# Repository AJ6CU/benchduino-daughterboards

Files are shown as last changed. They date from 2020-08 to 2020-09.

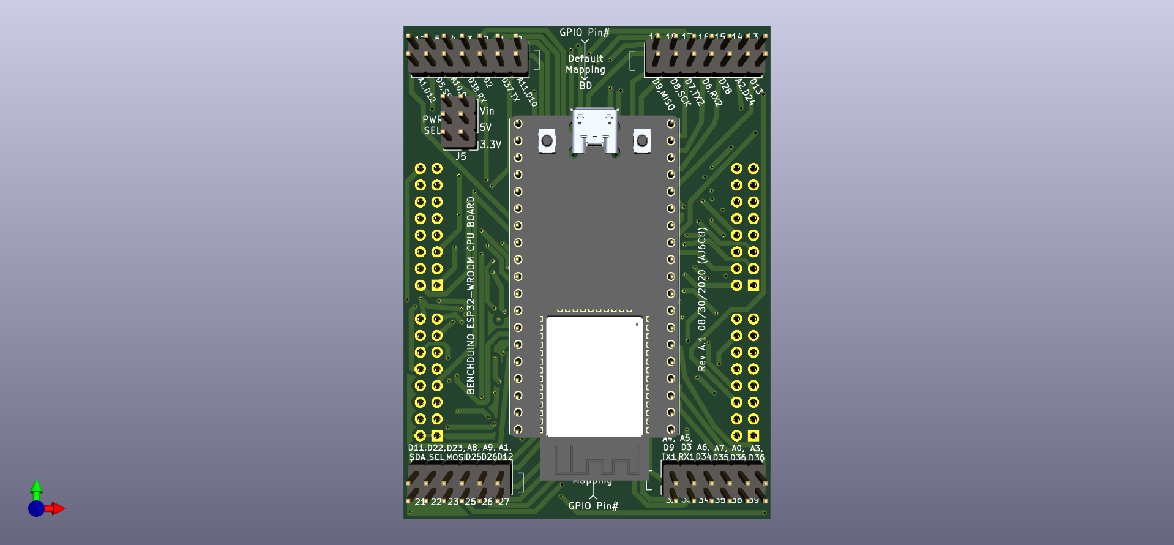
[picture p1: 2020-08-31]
ESP32-WROOM/Documentation/BenchDuino ESP32-WROOM-32 CPU Board.png

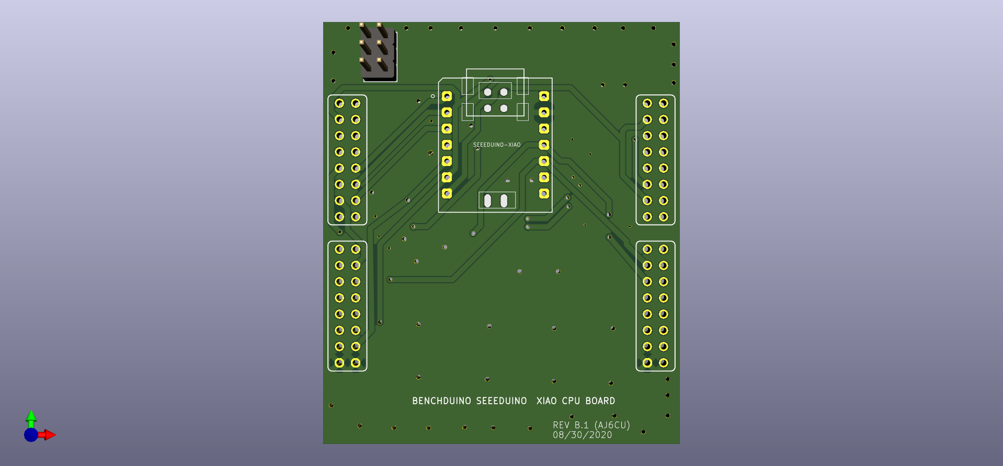
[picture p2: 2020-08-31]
Seeeduino XIAO/Documentation/Seeeduino XIAO CPU Board.png

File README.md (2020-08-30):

# CPU Daughterboards Benchduino
 
www.hamradioworkbench.com has designed and sells a general purpose development
board for Microcontrollers. They have provided the designs for both the CPU
Daughterboards as wells as the addon Prototype board.

This repository contains additional CPU Daughterboards that I have designed.

Subdirectories include:
- Gerbers - this directory includes a zip file that you should be able to upload to
            your favorite Fab house.
- PCBDesign - Most of the designs are done with KiCad. A few of the earlier ones
            were done with Eagle. The subdirectory will indentify which tool was used. 
- Documentation - This directory contains a schematic (pdf format) and pinmapping between
            the Benchduino pins and the pins on the Microcontroller. Please note that
            some physical pins on the Microcontroller might be mapped to multiple 
            locations on the Benchduino. Please use this pinmapping document along
            with your favorite pinout diagram to understand which pins could cause
            conflicts.
- Examples - Generally I have provide a code example (typically derived from the
            original Hamvention code of the published on the hamradioworkbench site)

There is absolutely no warranty here. Use this at your own risk!

73
Mark Hatch
AJ6CU

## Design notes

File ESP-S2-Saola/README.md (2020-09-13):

# ESP-S2-Saola CPU Daughterboard for Benchduino
 
www.hamradioworkbench.com has designed and sells a general purpose development
board for Microcontrollers. They have provided the designs for both the CPU
Daughterboards as wells as the addon Prototype board.

This directory contains the CPU Daughterboards for the ESP-S2-Saola processor.

*IMPORTANT*
There are many different versions of the ESP32. This design was built around:

https://www.amazon.com/gp/product/B087T2NTD6/ref=ppx_yo_dt_b_search_asin_title?ie=UTF8&psc=1

Just because your board has the same number of pins, it may not work...  There are also 
different widths of boards, the latter ones being slightly wider.

Subdirectories include:
- Gerbers - this directory includes a zip file that you should be able to upload to
            your favorite Fab house.
- PCBDesign - Most of the designs are done with KiCad. A few of the earlier ones
            were done with Eagle. The subdirectory will indentify which tool was used. 
- Documentation - This directory contains a schematic (pdf format) and pinmapping between
            the Benchduino pins and the pins on the Microcontroller. Please note that
            some physical pins on the Microcontroller might be mapped to multiple 
            locations on the Benchduino. Please use this pinmapping document along
            with your favorite pinout diagram to understand which pins could cause
            conflicts.
- Examples - Generally I have provide a code example (typically derived from the
            original Hamvention code of the published on the hamradioworkbench site).
            Make sure you read the "README" file in this directory as often there are
            significant porting issues that you might need to be aware of in your
            own applications.

There is absolutely no warranty here. Use this at your own risk!

73
Mark Hatch
AJ6CU

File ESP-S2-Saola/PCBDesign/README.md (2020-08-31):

# ESP-S2-Saola CPU Daughterboard for Benchduino
 
www.hamradioworkbench.com has designed and sells a general purpose development
board for Microcontrollers. They have provided the designs for both the CPU
Daughterboards as wells as the addon Prototype board.

This directory contains the design files for the ESP-S2-Saola CPU Daughterboard. This
design was done in KiCad.

The zip file is a KiCad archive that you shoule be able to just expand.

There is absolutely no warranty here. Use this at your own risk!

73
Mark Hatch
AJ6CU

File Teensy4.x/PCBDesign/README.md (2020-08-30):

# Teensy 4/4.1 CPU Daughterboard for Benchduino
 
www.hamradioworkbench.com has designed and sells a general purpose development
board for Microcontrollers. They have provided the designs for both the CPU
Daughterboards as wells as the addon Prototype board.

This directory contains the design files for the Teensy 4/4.1 CPU Daughterboards. This
design was done in Eagle.

There is absolutely no warranty here. Use this at your own risk!

73
Mark Hatch
AJ6CU

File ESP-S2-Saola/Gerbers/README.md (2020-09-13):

# ESP-S2-Saola CPU Daughterboard for Benchduino
 
www.hamradioworkbench.com has designed and sells a general purpose development
board for Microcontrollers. They have provided the designs for both the CPU
Daughterboards as wells as the addon Prototype board.

This directory contains a Zip file with the Gerbers for the CPU Daughterboard for a 
ESP-S2-Saola processor.

This design has been fabricated using these Gerbers and successfully runs the 
Hamvention demo program.

There is absolutely no warranty here. Use this at your own risk!

73
Mark Hatch
AJ6CU

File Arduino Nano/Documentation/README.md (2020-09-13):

# Documentation for Arduino Nano CPU Daughterboard
 
www.hamradioworkbench.com has designed and sells a general purpose development
board for Microcontrollers. They have provided the designs for both the CPU
Daughterboards as wells as the addon Prototype board.

This directory contains the documentation for this design. Including: 
- Schematic (pdf format) 
- Pinmapping between the Benchduino pins and the pins on the Microcontroller. 
            to multiple locations on the Benchduino. Please use this pinmapping 
            document along with your favorite pinout diagram to understand which 
            pins could cause
            conflicts.
            
*IMPORTANT NOTE ON POWER*
This microcontroller has 2 jumpers at the top of the board that allow you to select
which power is fed to the board *AND* whether in the case where the processor is
being powered by USB, the 5V is passed back to the Benchduino motherboard.

NOTE: Generally it is not recommended to power the processor from USB *and* also via
the 5v/3v/Vin power. 

Vin: This pin should generally not be jumpered unless you know what you are doing. When
jumpered, it provides power to the processor. The only problem is that the Benchduino
motherboard *does not* provide power to this pin. It is left floating. So if you want to
use this pin, perhaps because you are using a battery, you *must* provide your own power
to this pin.

5+: This pin is both input and output. When the motherboard of the benchduino is powered
(i.e. a power source is plugged into the barrel connector) 5V is delivered to the
daughterboard. However, in the case where the processor is being powered by the USB
connection, the 5V from the USB is distributed *to* the benchduino motherboard and
used to power various devices you might have. 

However...
you might want to consider removing this jumper if you are powering the processor
by USB and *do not* want the peripherals driven off this power source because of the current
drain. In such a case, remove this jumper and power the Benchduino via the barrel
connector.

NOTE: Even though some people have hacked their Nano to run on 3.3v (involves lowering
clock speed plus more - google it), I did not connect 3.3V in. If you want to run your
Nano on something other than the 5V spec, you can use the Vin pin on the Benchduino
motherboard and then jumper the Vin pin described above.

There is absolutely no warranty here. Use this at your own risk!

73
Mark Hatch
AJ6CU

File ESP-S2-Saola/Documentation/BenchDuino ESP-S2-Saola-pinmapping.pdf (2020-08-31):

ESP32 Saola Pin Mapping to Benchduino

<------------------------------------------Saola------------------------------------------><-------------BD------------>
Pin# | GPIO# | Analog | Analog Ch | Spc Analog | Special | Analog | Digital | SPC
1 | 3.3v
2 | GPIO00
3 | GPIO01 | 0 | ADC1_CH0 | Touch1 | | 0
4 | GPIO02 | 1 | ADC1_CH1 | Touch2 | | 1 | 2
5 | GPIO03 | 2 | ADC1_CH2 | Touch3 | | 2 | 3
6 | GPIO04 | 3 | ADC1_CH3 | Touch4 | | 3 | 4
7 | GPIO05 | 4 | ADC1_CH4 | Touch5 | | 4 | 5
8 | GPIO06 | 5 | ADC1_CH5 | Touch6 | | 5 | 6
9 | GPIO07 | 6 | ADC1_CH6 | Touch7 | | 6 | 7
10 | GPIO08 | 7 | ADC1_CH7 | Touch8 | | 7 | 8
11 | GPIO09 | 8 | ADC1_CH8 | Touch9 | | 8 | 9
12 | GPIO10 | 9 | ADC1_CH9 | Touch10 | | 9 | 10
13 | GPIO11 | 10 | ADC2_CH0 | Touch11 | | 10 | 11 | CS
14 | GPIO12 | 11 | ADC2_CH1 | Touch12 | | 11 | 12 | MOSI
15 | GPIO13 | 12 | ADC2_CH2 | Touch13 | | | 13 | CLK
16 | GPIO14 | 13 | ADC2_CH3 | Touch14 | | | 24 | MISO
17 | GPIO15 | 14 | ADC2_CH4 | XTAL_32k_P | U0RTS | | 25
18 | GPIO16 | 15 | ADC2_CH5 | XTAL_32k_N | U0CTS | | 26
19 | GPIO17 | 16 | ADC2_CH6 | DAC1 | U1TXD | | 27 | TX1
20 | 5.0Vin
21 | Gnd
22 | GPIO18 | 17 | ADC2_CH7 | DAC2 | U1RXD | | 28 | RX1
23 | GPIO19 | 18 | ADC2_CH8 | USB_D- | U1RTS | | 29
24 | GPIO20 | 19 | ADC2_CH9 | USB_D+ | U1CTS | | 30
25 | GPIO21 | | | | | | 31
26 | GPIO26 | | | | | | 32
27 | GPIO33 | | | | | | 33
28 | GPIO34 | | | | | | 34
29 | GPIO35 | | | | | | 35
30 | GPIO36 | | | | | | 36
31 | GPIO37 | | | | | | 37
32 | GPIO38 | | | | | | 38
33 | GPIO39 | | | | | | 22 | SDA
34 | GPIO40 | | | | | | 23 | SCL
35 | GPIO41
36 | GPIO42
37 | GPIO43 | | | | U0TX0 | | | TX
38 | GPIO44 | | | | U0RX0 | | | RX
39 | GPIO45
40 | GPIO46
41 | Reset
42 | Gnd

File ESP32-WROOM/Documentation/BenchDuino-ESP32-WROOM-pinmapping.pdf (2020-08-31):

ESP32 WROOM Pin Mapping to Benchduino

<--------------------ESP32-WROOM--------------------> | <-------------------BD----------------->
Pin# | GPIO | Analog | SPC | Analog | Digital | SPC
25 | GPIO0 | ADC11 | | 11 | 10
35 | GPIO1 | | TX0 | | 37 | TX
24 | GPIO2 | ADC12 | | X | 2
34 | GPIO3 | | RX0 | | 38 | RX
26 | GPIO4 | ADC10 | | 10 | 4
29 | GPIO5 | | SS | | 5 | SS
20 | GPIO6
21 | GPIO7
22 | GPIO8
16 | GPIO9 | | RX1
17 | GPIO10 | | TX1
18 | GPIO11
13 | GPIO12 | ADC15 | | 1 | 12
15 | GPIO13 | ADC14 | | X | 13
12 | GPIO14 | ADC16 | | 2 | 24
23 | GPIO15 | ADC13 | | X | 28
27 | GPIO16 | | RX2 | | 6 | RX2
28 | GPIO17 | | TX2 | | 7 | TX2
30 | GPIO18 | | SCK | | 8 | SCK
31 | GPIO19 | | MISO | | 29 | MISO
33 | GPIO21 | | SDA | | 11 | SDA
36 | GPIO22 | | SCL | | 22 | SCL
37 | GPIO23 | | MOSI | | 23 | MOSI
9 | GPIO25 | ADC18 | | 8 | 25
10 | GPIO26 | ADC19 | | 9 | 26
11 | GPIO27 | ADC17 | | x | 27
7 | GPIO32 | ADC4 | | 4 | 9 | TX1
8 | GPIO33 | ADC5 | | 5 | 3 | RX1
5 | GPIO34 | ADC6 | | 6 | 34
6 | GPIO35 | ADC7 | | 7 | 35
3 | GPIO36 | ADC0 | | 0 | 36
4 | GPIO39 | ADC3 | | 3 | 33

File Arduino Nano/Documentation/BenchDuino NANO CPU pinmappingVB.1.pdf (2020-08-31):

Nano Pin Mapping to Benchduino

Nano Pin | BD Analog | BD Digital | BD Special
A0 | A0
A1 | A1
A2 | A2
A3 | A3
A4 | A4 | | SDA
A5 | A5 | | SCL
A6 | A6
A7 | A7
AREF | | | REF
D0 | | | RX
D1 | | | TX
D2 | | D2
D3 | | D3
D4 | | D4
D5 | | D5
D6 | | D6
D7 | | D7
D8 | | D8
D9 | | D9
D10 | | D10 | SS
D11 | | D11 | MOSI
D12 | | D12 | MISO
D13 | | D13 | SCK

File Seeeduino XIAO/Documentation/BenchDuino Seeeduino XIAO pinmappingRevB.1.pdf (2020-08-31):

Xiao Pin Mapping to Benchduino

XIAO Pin | BD Analog | BD Digital | BD Special
A0 | A0
A1 | A1
A2 | A2 | D2
A3 | A3 | D3
A4 | A4 | D4 | SDA
A5 | A5 | D5 | SCL
A6 | A6 | D6 | TX
A7 | A7 | D7 | RX
A8 | A8 | D8 | SCK
A9 | A9 | D9 | MISO
A10 | A10 | D10 | MOSI

Note: D0 and D1 are connected to A0 and A1 and not the usual RX and TX pins

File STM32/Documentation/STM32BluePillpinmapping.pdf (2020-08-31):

BluePill Pin Mapping to Benchduino

stm32 pin BD Analog BD Digital BD Special PA0
PA1
PA2 | A2 | D2 | TX2
PA3 | A3 | D3 | RX2
PA4 | A4 | D4 | SS1
PA5 | A5 | D5 | SCK1
PA6 | A6 | D6 | MISO1
PA7 | A7 | D7 | MOSI1
PA8 | | D8
PA9 | | D9 | TX1
PA10 | | D10 | RX1
PA11 | | D11
PA12 | | D12
PA13 | NC - Serial programming header
PA14 | NC - Serial programming header
PA15 | See Extra hdr
PB0 | See Extra hdr
PB1 | See Extra hdr
PB2 | NC - Boot programming header
PB3 | | D23
PB4 | | D24
PB5 | | D25
PB6 | | D26 | SCL1
PB7 | | D27 | SDA1
PB8 | | D28
PB9 | | D29
PB10 | | D30 | TX3
PB11 | | D31 | RX3
PB12 | | D32
PB13 | | D33
PB14 | | D34
PB15 | | D35

Extra Header
PA0
PA1
PA15
PB0
PB1
PC13
PC14
PC15

VBAT
GND

Benchduino with No connections
NC | D13
NC | D22
NC | D36
NC | D37
NC | D38
NC | A8
NC | A9
NC | A10
NC | A11

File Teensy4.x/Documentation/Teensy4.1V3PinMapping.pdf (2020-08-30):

Teensy 4.1 Pin Mapping to Benchduino

Teensy Pin | BD Analog | BD Digital | BD Special
3.3V | 3V
3.3V max | 3V Out
A0 | A0 | D14 | TX3
A1 | A1 | D15 | RX3
A2 | A2
A3 | A3
A4 | A4 | D20 | SDA
A5 | A5 | D21 | SCL
A6 | A6
A7 | A7
A8 | A8 | D22
A9 | A9 | D23
A10 | A10 | D24
A11 | A11 | D25
A12 | | D26
A13 | | D27
A14 | | D38
D0 | | | Rx1
D1 | | | Tx1
D2 | | D2
D3 | | D3
D4 | | D4
D5 | | D5
D6 | | D6
D7 | | D17 | Rx2
D7 | | D7 | RX2
D8 | | D16 | Tx2
D9 | | D9
D10 | | D10 | SS
D11 | | D11 | MOSI
D12 | | D12 | MISO
D13 | | D13 | SCK
D26 | | D26
D27 | | D27
D28 | | D28
D29 | | D29
D30 | | D30
D31 | | D31
D32 | | D32
D33 | | D33
D34 | | D34
D35 | | D35

D36 | D36
D37 | D37
D38 | D38

Extra Header
A15 | D39
A16 | D40
A17 | D41
VBAT
GND
NC | 5V IN
NC | AREF
NC | Reset

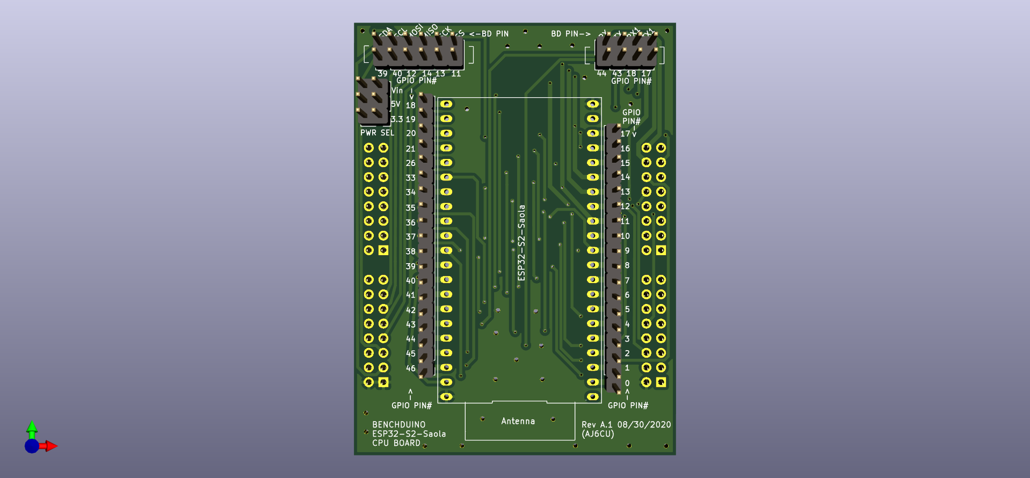
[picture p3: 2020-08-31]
ESP-S2-Saola/Documentation/BenchDuino ESP-S2-Saola CPU Board.png

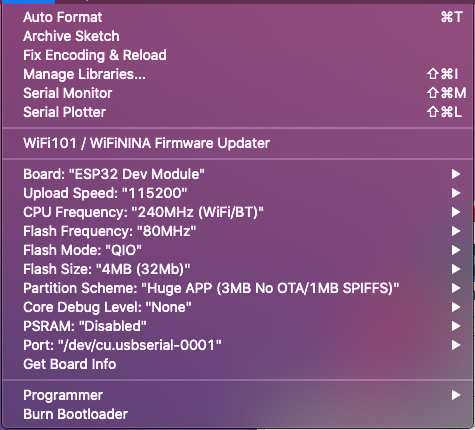
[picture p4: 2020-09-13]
ESP32-WROOM/Documentation/BenchDuino ESP32-ArduinoIDEConfig.png

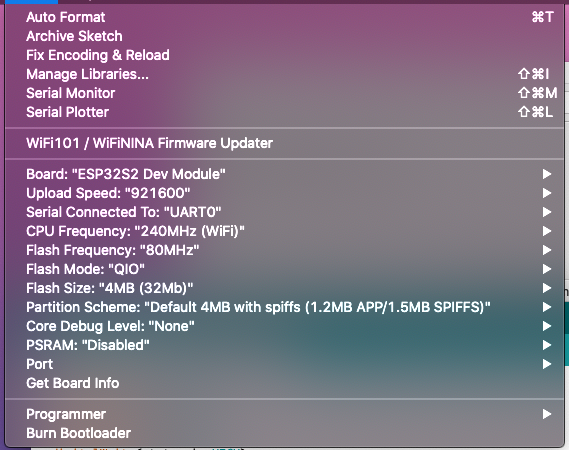
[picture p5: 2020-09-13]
ESP-S2-Saola/Documentation/BenchDuino ESP-S2-ArduinoConfig.png

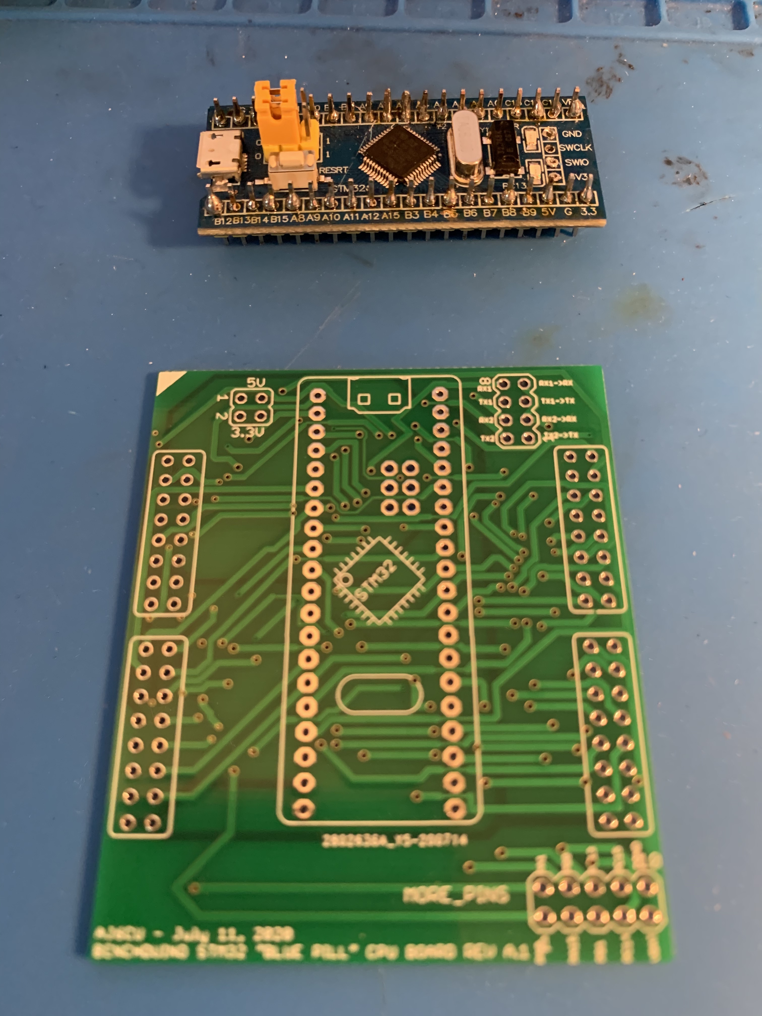
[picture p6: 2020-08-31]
STM32/Documentation/bluepilldaughter.jpg

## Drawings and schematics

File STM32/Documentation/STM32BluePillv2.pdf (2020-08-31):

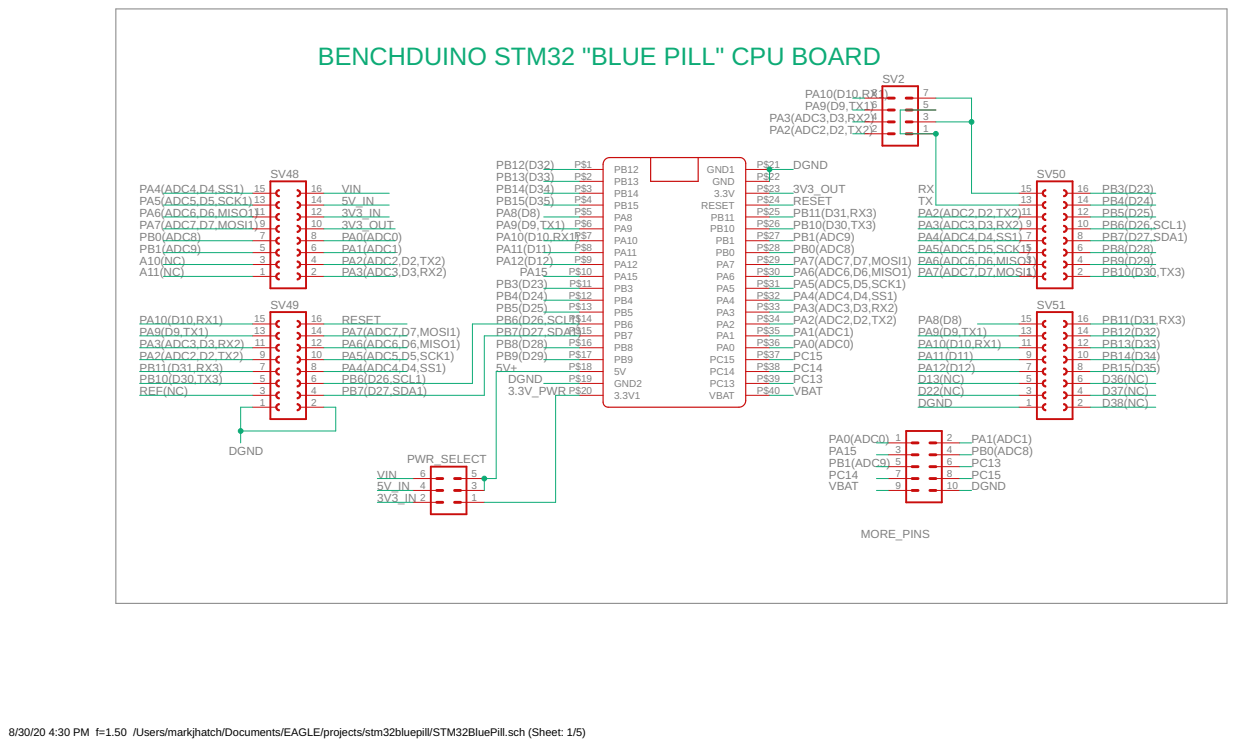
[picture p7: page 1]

BENCHDUINO STM32 "BLUE PILL" CPU BOARD

8/30/20 4:30 PM f=1.50 /Users/markjhatch/Documents/EAGLE/projects/stm32bluepill/STM32BluePill.sch (Sheet: 1/5)

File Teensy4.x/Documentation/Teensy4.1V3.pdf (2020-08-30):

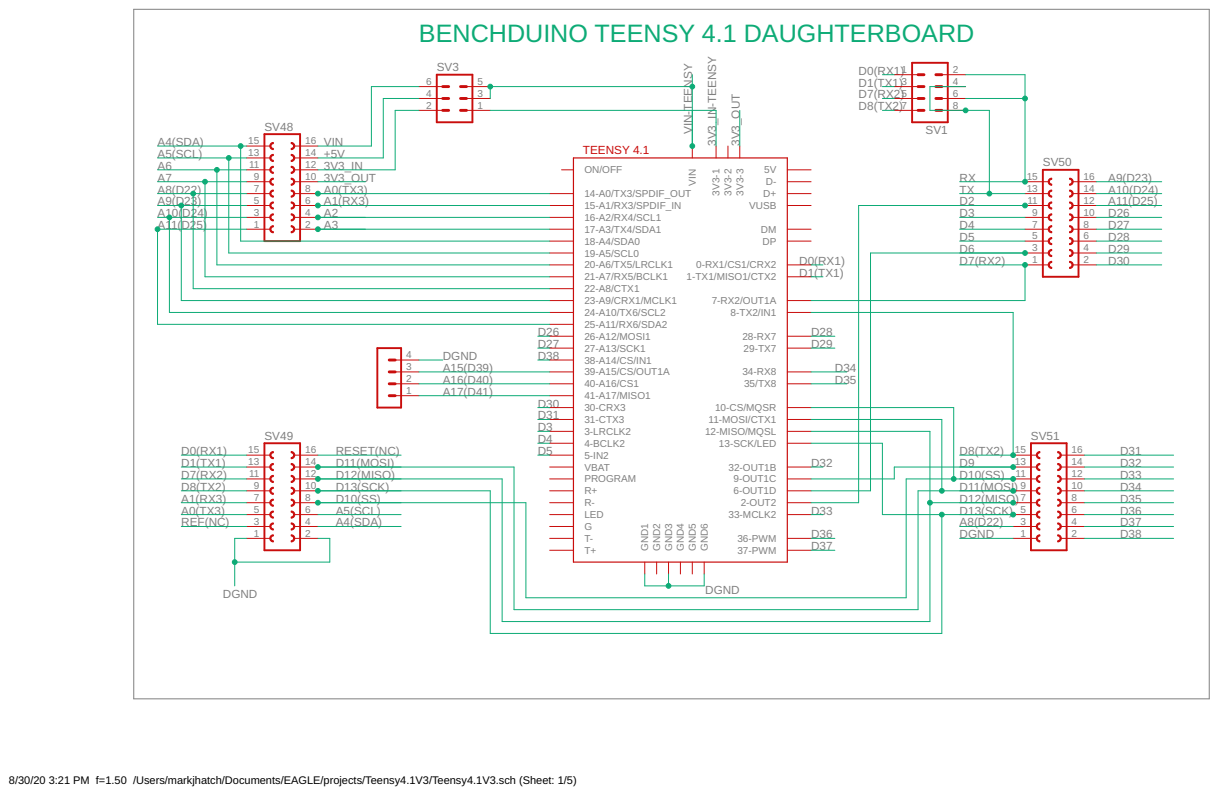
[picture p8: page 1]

8/30/20 3:21 PM f=1.50 /Users/markjhatch/Documents/EAGLE/projects/Teensy4.1V3/Teensy4.1V3.sch (Sheet: 1/5)

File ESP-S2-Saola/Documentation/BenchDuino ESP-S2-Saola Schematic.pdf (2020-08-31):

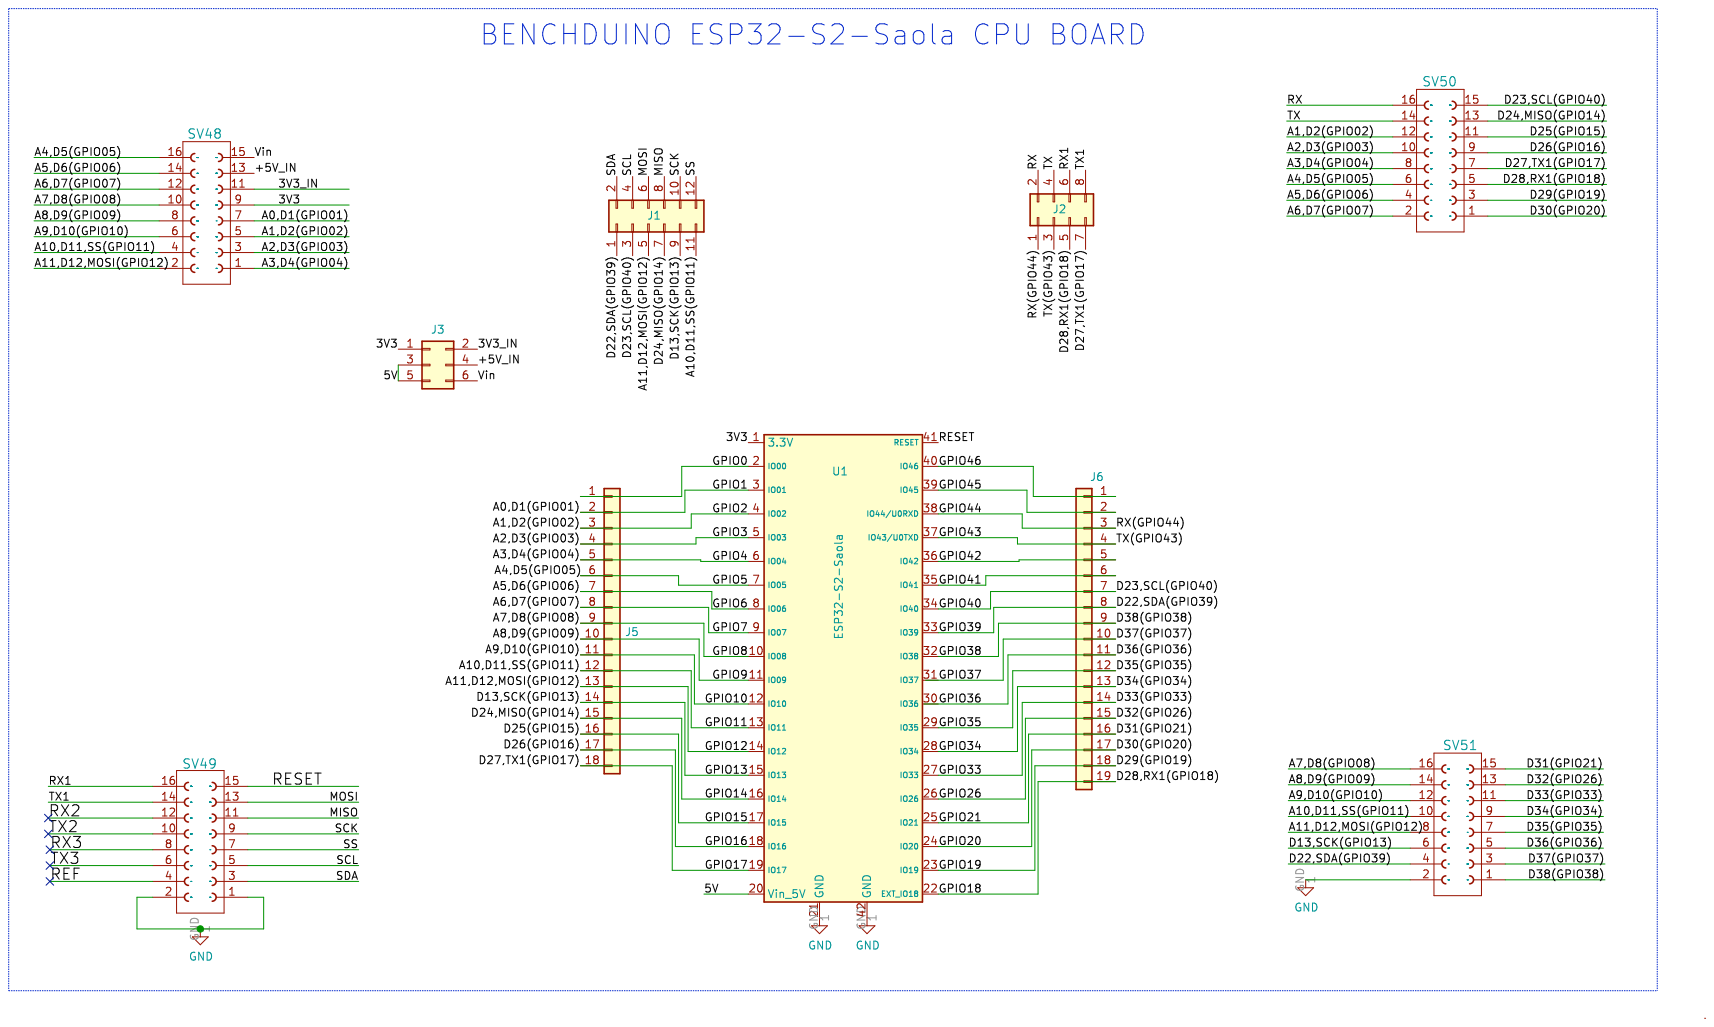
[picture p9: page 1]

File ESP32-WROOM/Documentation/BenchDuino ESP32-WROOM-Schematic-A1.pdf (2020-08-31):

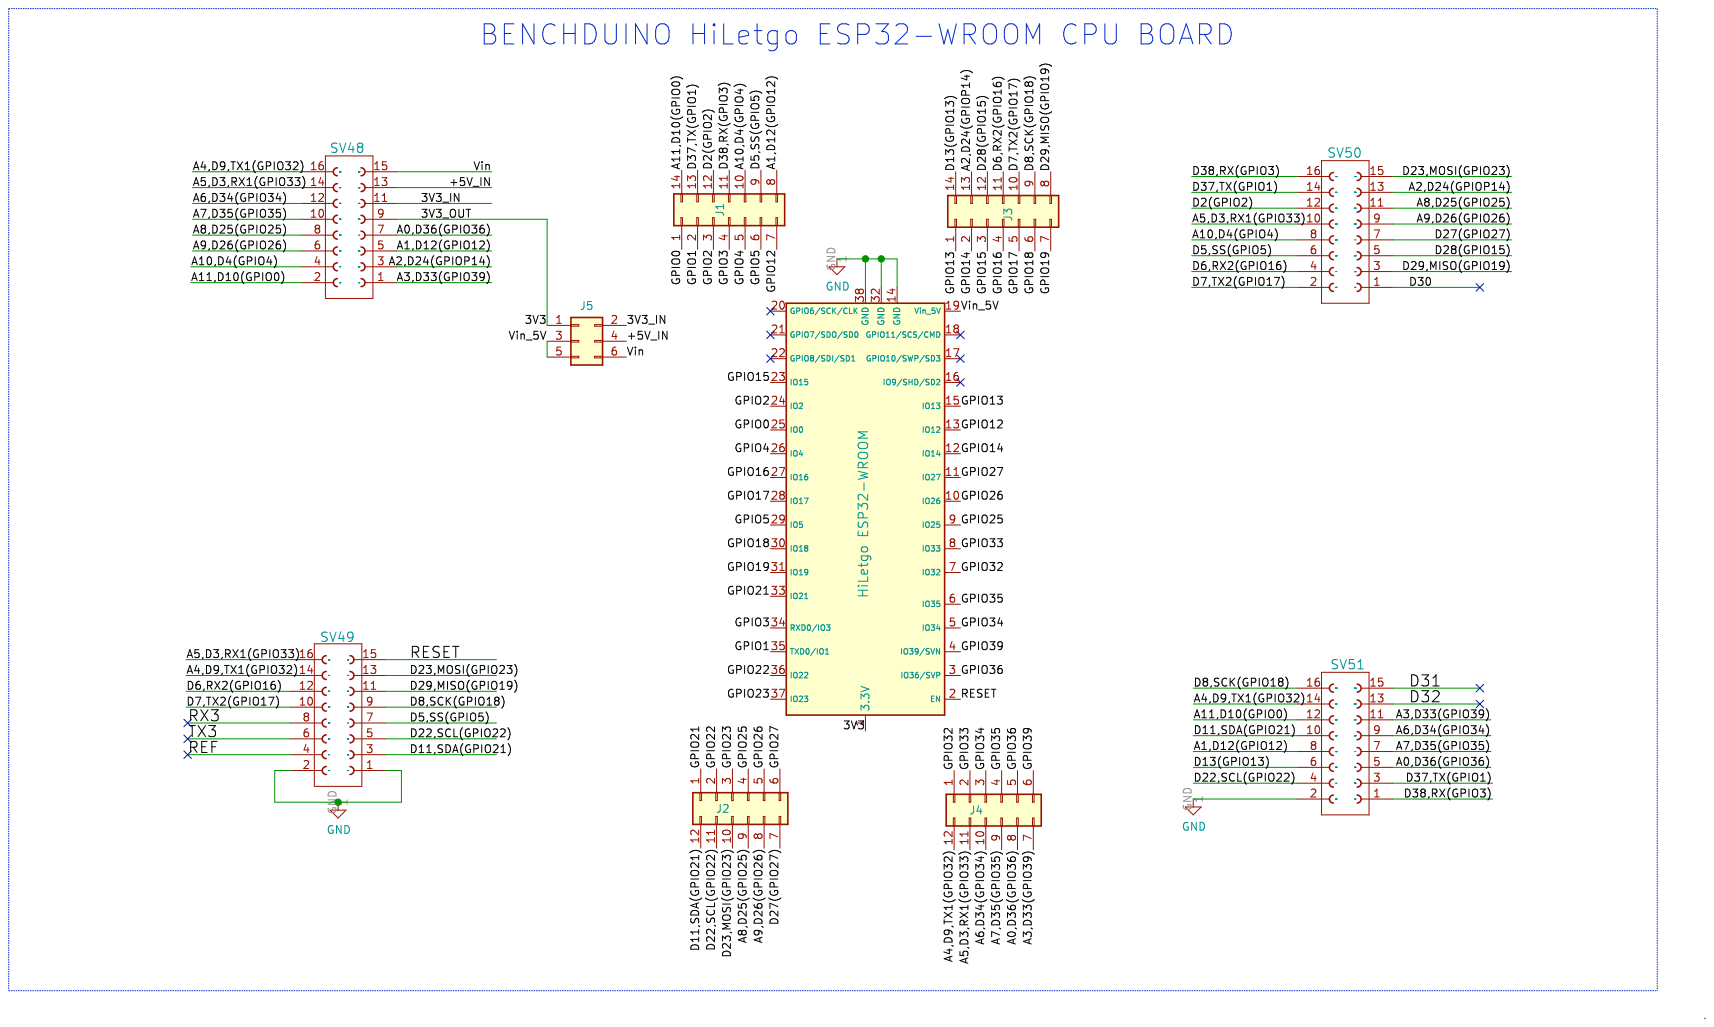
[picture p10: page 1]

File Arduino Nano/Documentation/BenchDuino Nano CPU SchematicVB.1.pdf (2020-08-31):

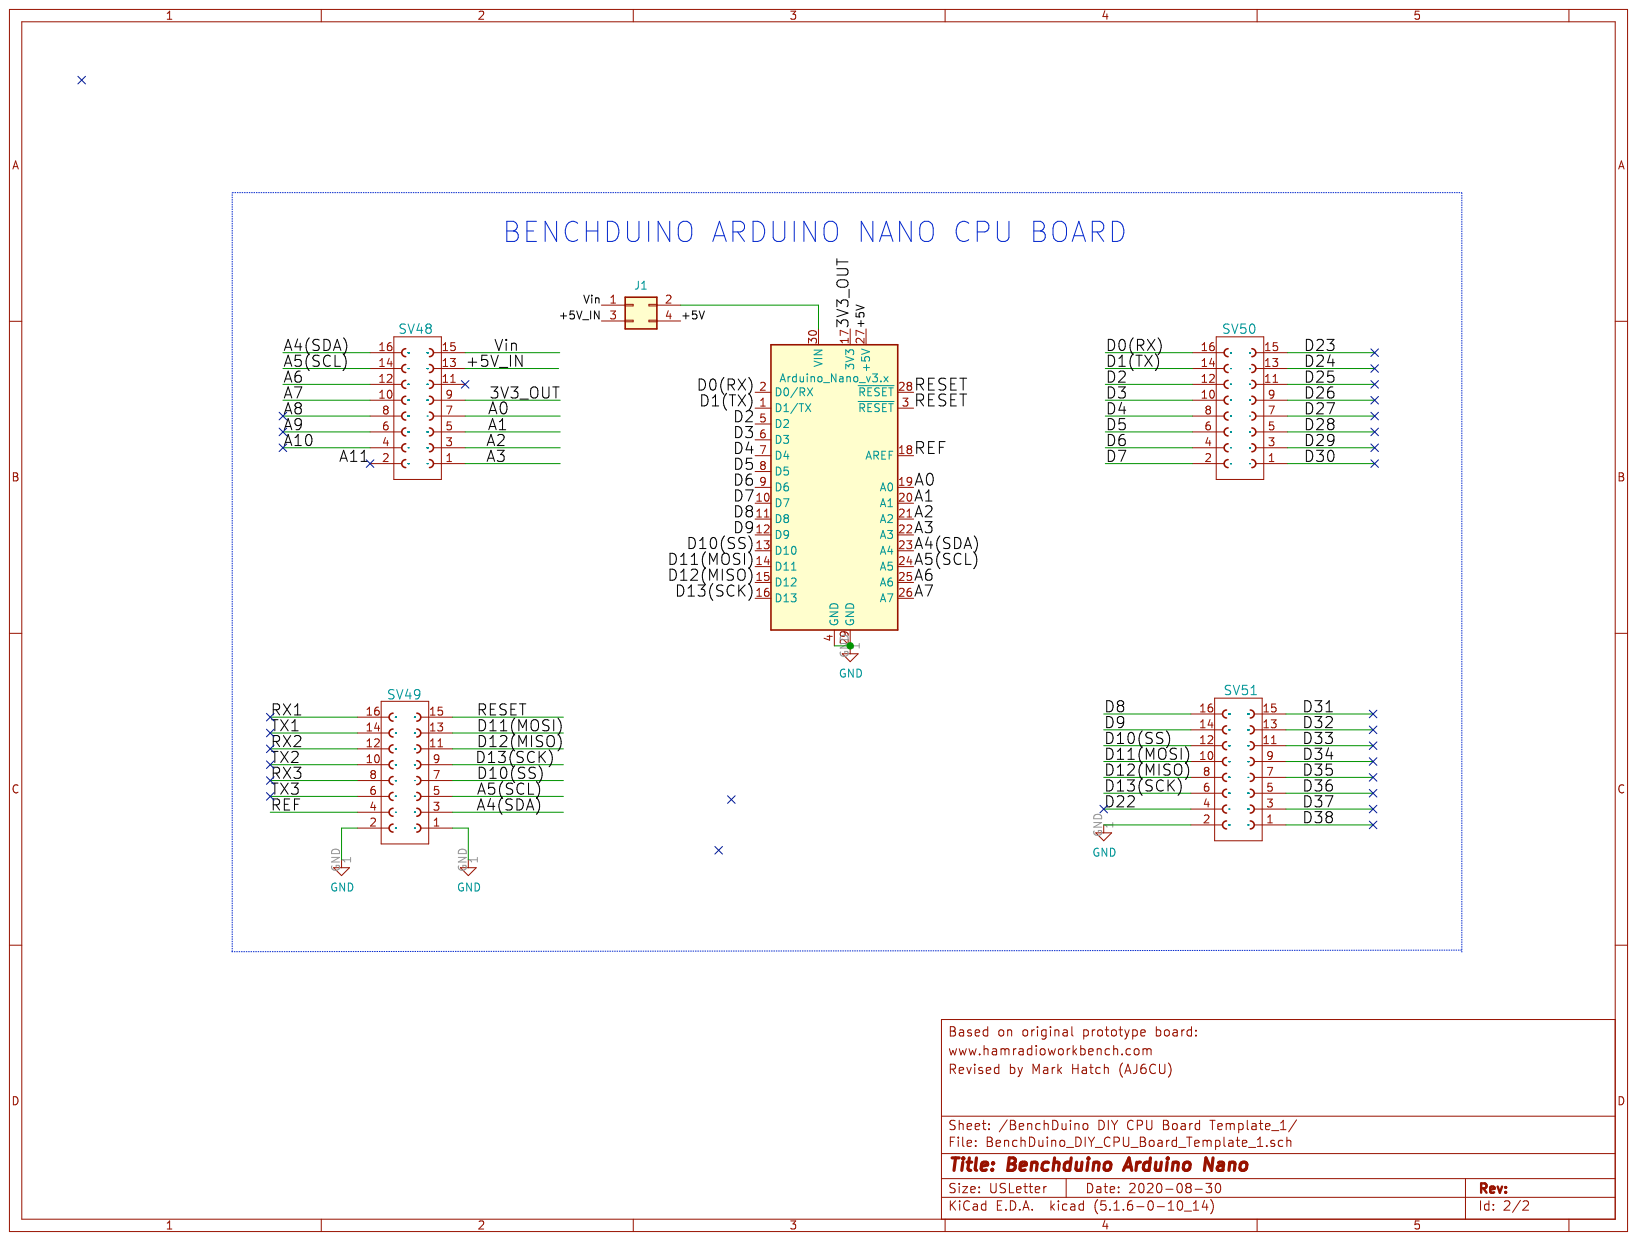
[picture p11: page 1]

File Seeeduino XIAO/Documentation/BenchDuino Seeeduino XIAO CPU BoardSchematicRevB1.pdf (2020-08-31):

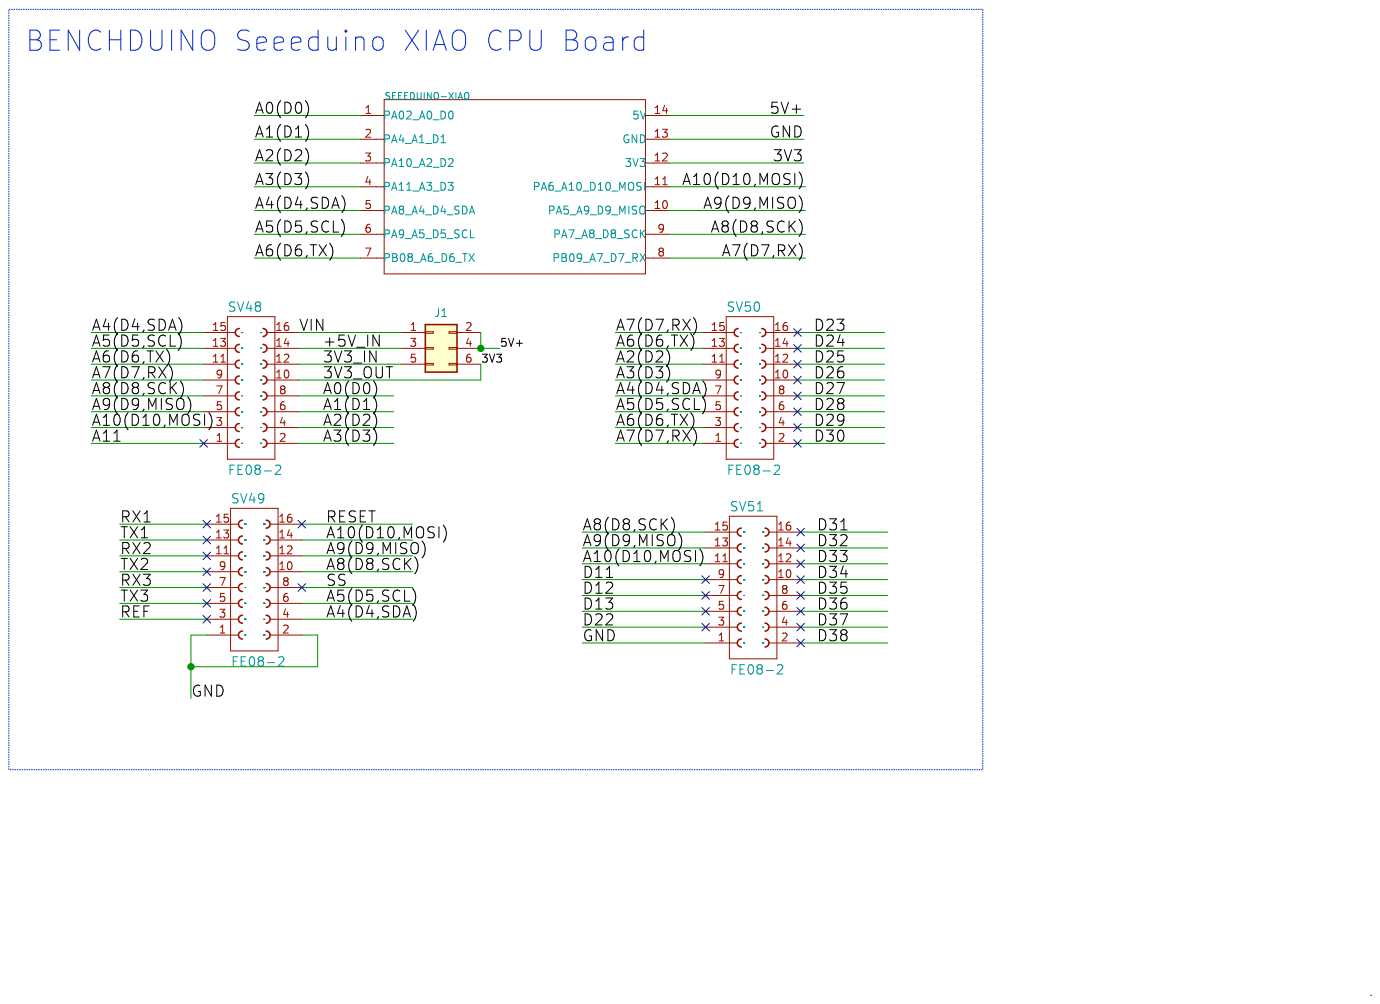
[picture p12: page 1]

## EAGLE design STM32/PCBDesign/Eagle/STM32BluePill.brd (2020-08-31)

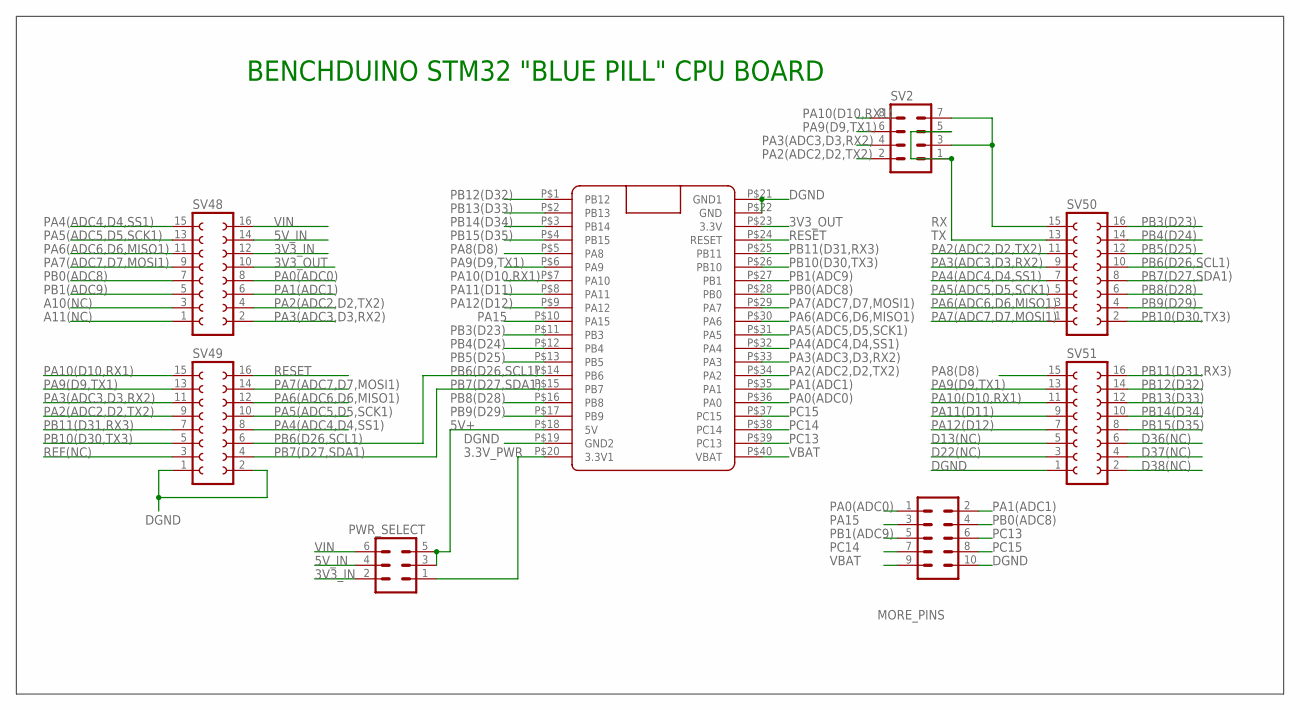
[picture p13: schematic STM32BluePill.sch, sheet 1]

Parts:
MORE_PINS: MA05-2
PWR_SELECT: MA03-2
SV2: MA04-2
SV48, SV49, SV50, SV51: FE08-2
U$1: BLUE_PILLADVANCED; BLUE_PILL_ADV

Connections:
3.3V_PWR: PWR_SELECT.1, U$1.P$20 (3.3V1)
3V3_IN: PWR_SELECT.2, SV48.12
3V3_OUT: SV48.10, U$1.P$23 (3.3V)
5V+: PWR_SELECT.3, PWR_SELECT.5, U$1.P$18 (5V)
5V_IN: PWR_SELECT.4, SV48.14
A10(NC): SV48.3
A11(NC): SV48.1
D13(NC): SV51.5
D22(NC): SV51.3
D36(NC): SV51.6
D37(NC): SV51.4
D38(NC): SV51.2
DGND: MORE_PINS.10, SV49.1, SV49.2, SV51.1, U$1.P$19 (GND2), U$1.P$21 (GND1), U$1.P$22 (GND)
PA0(ADC0): MORE_PINS.1, SV48.8, U$1.P$36 (PA0)
PA1(ADC1): MORE_PINS.2, SV48.6, U$1.P$35 (PA1)
PA2(ADC2,D2,TX2): SV2.2, SV48.4, SV49.9, SV50.11, U$1.P$34 (PA2)
PA3(ADC3,D3,RX2): SV2.4, SV48.2, SV49.11, SV50.9, U$1.P$33 (PA3)
PA4(ADC4,D4,SS1): SV48.15, SV49.8, SV50.7, U$1.P$32 (PA4)
PA5(ADC5,D5,SCK1): SV48.13, SV49.10, SV50.5, U$1.P$31 (PA5)
PA6(ADC6,D6,MISO1): SV48.11, SV49.12, SV50.3, U$1.P$30 (PA6)
PA7(ADC7,D7,MOSI1): SV48.9, SV49.14, SV50.1, U$1.P$29 (PA7)
PA8(D8): SV51.15, U$1.P$5 (PA8)
PA9(D9,TX1): SV2.6, SV49.13, SV51.13, U$1.P$6 (PA9)
PA10(D10,RX1): SV2.8, SV49.15, SV51.11, U$1.P$7 (PA10)
PA11(D11): SV51.9, U$1.P$8 (PA11)
PA12(D12): SV51.7, U$1.P$9 (PA12)
PA15: MORE_PINS.3, U$1.P$10 (PA15)
PB0(ADC8): MORE_PINS.4, SV48.7, U$1.P$28 (PB0)
PB1(ADC9): MORE_PINS.5, SV48.5, U$1.P$27 (PB1)
PB3(D23): SV50.16, U$1.P$11 (PB3)
PB4(D24): SV50.14, U$1.P$12 (PB4)
PB5(D25): SV50.12, U$1.P$13 (PB5)
PB6(D26,SCL1): SV49.6, SV50.10, U$1.P$14 (PB6)
PB7(D27,SDA1): SV49.4, SV50.8, U$1.P$15 (PB7)
PB8(D28): SV50.6, U$1.P$16 (PB8)
PB9(D29): SV50.4, U$1.P$17 (PB9)
PB10(D30,TX3): SV49.5, SV50.2, U$1.P$26 (PB10)
PB11(D31,RX3): SV49.7, SV51.16, U$1.P$25 (PB11)
PB12(D32): SV51.14, U$1.P$1 (PB12)
PB13(D33): SV51.12, U$1.P$2 (PB13)
PB14(D34): SV51.10, U$1.P$3 (PB14)
PB15(D35): SV51.8, U$1.P$4 (PB15)
PC13: MORE_PINS.6, U$1.P$39 (PC13)
PC14: MORE_PINS.7, U$1.P$38 (PC14)
PC15: MORE_PINS.8, U$1.P$37 (PC15)
REF(NC): SV49.3
RESET: SV49.16, U$1.P$24 (RESET)
RX: SV2.3, SV2.7, SV50.15
TX: SV2.1, SV2.5, SV50.13
VBAT: MORE_PINS.9, U$1.P$40 (VBAT)
VIN: PWR_SELECT.6, SV48.16

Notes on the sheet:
BENCHDUINO STM32 "BLUE PILL" CPU BOARD

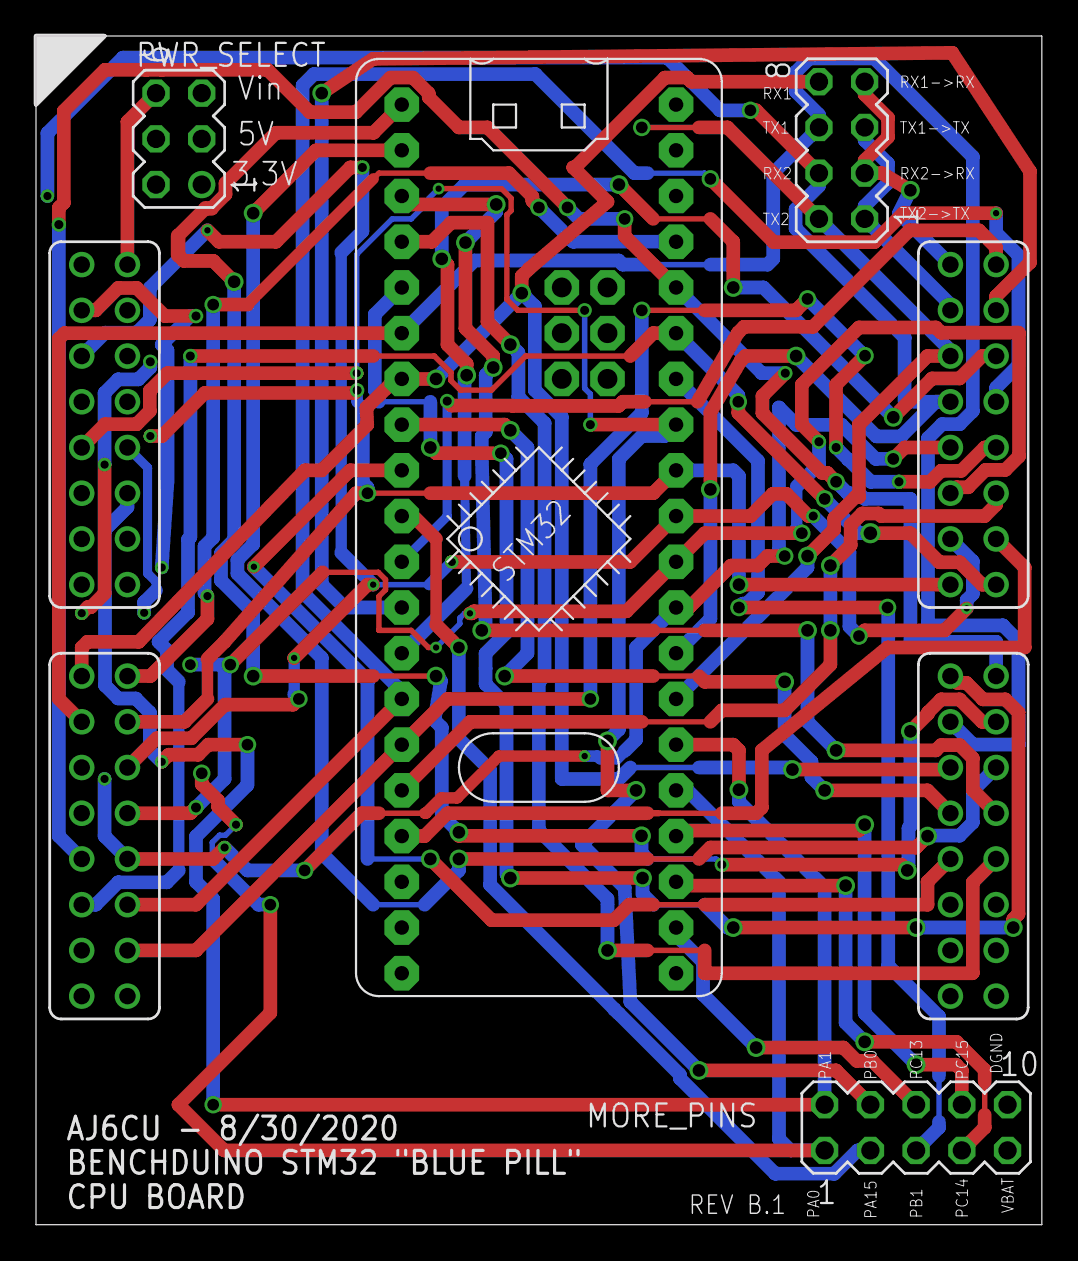
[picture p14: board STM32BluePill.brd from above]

Board: 4 copper layers, 55.9 x 66.0 mm, 8 parts (0 on the bottom side), 43 nets.

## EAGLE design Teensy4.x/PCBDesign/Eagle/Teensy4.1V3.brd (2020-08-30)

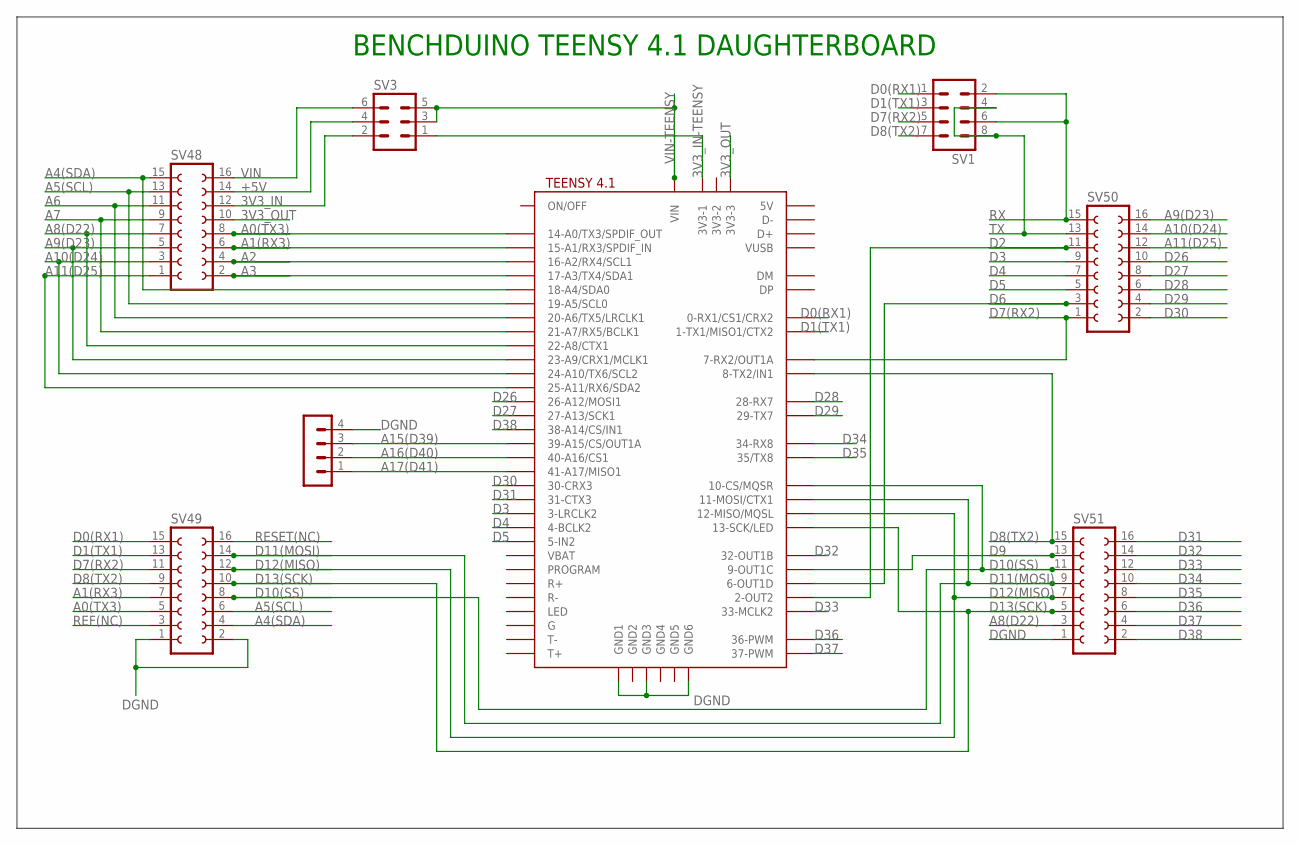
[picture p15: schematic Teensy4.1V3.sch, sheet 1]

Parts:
SV1: MA04-2
SV3: MA03-2
SV4: MA04-1
SV48, SV49, SV50, SV51: FE08-2
U$1: TEENSY41

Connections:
3V3_IN: SV3.2, SV48.12
3V3_IN-TEENSY: SV3.1, U$1.3V3-1
3V3_OUT: SV48.10, U$1.3V3-3
+5V: SV3.4, SV48.14
A0(TX3): SV48.8, SV49.5, U$1.14-A0/TX3/SPDIF_OUT
A1(RX3): SV48.6, SV49.7, U$1.15-A1/RX3/SPDIF_IN
A2: SV48.4, U$1.16-A2/RX4/SCL1
A3: SV48.2, U$1.17-A3/TX4/SDA1
A4(SDA): SV48.15, SV49.4, U$1.18-A4/SDA0
A5(SCL): SV48.13, SV49.6, U$1.19-A5/SCL0
A6: SV48.11, U$1.20-A6/TX5/LRCLK1
A7: SV48.9, U$1.21-A7/RX5/BCLK1
A8(D22): SV48.7, SV51.3, U$1.22-A8/CTX1
A9(D23): SV48.5, SV50.16, U$1.23-A9/CRX1/MCLK1
A10(D24): SV48.3, SV50.14, U$1.24-A10/TX6/SCL2
A11(D25): SV48.1, SV50.12, U$1.25-A11/RX6/SDA2
A15(D39): SV4.3, U$1.39-A15/CS/OUT1A
A16(D40): SV4.2, U$1.40-A16/CS1
A17(D41): SV4.1, U$1.41-A17/MISO1
D0(RX1): SV1.1, SV49.15, U$1.0-RX1/CS1/CRX2
D1(TX1): SV1.3, SV49.13, U$1.1-TX1/MISO1/CTX2
D2: SV50.11, U$1.2-OUT2
D3: SV50.9, U$1.3-LRCLK2
D4: SV50.7, U$1.4-BCLK2
D5: SV50.5, U$1.5-IN2
D6: SV50.3, U$1.6-OUT1D
D7(RX2): SV1.5, SV49.11, SV50.1, U$1.7-RX2/OUT1A
D8(TX2): SV1.7, SV49.9, SV51.15, U$1.8-TX2/IN2 (8-TX2/IN1)
D9: SV51.13, U$1.9-OUT1C
D10(SS): SV49.8, SV51.11, U$1.10-CS\MQSR (10-CS/MQSR)
D11(MOSI): SV49.14, SV51.9, U$1.11-MOSI/CTX1
D12(MISO): SV49.12, SV51.7, U$1.12-MISO/MQSL
D13(SCK): SV49.10, SV51.5, U$1.13-SCK/LED
D26: SV50.10, U$1.26-A12/MOSI1
D27: SV50.8, U$1.27-A13/SCK1
D28: SV50.6, U$1.28-RX7
D29: SV50.4, U$1.29-TX7
D30: SV50.2, U$1.30-CRX3
D31: SV51.16, U$1.31-CTX3
D32: SV51.14, U$1.32-OUT1B
D33: SV51.12, U$1.33-MCLK2
D34: SV51.10, U$1.34-RX8
D35: SV51.8, U$1.35-TX8 (35/TX8)
D36: SV51.6, U$1.36-PWM
D37: SV51.4, U$1.37-PWM
D38: SV51.2, U$1.38-A14/CS/IN1
DGND: SV4.4, SV49.1, SV49.2, SV51.1, U$1.GND1, U$1.GND3, U$1.GND6
REF(NC): SV49.3
RESET(NC): SV49.16
RX: SV1.2, SV1.6, SV50.15
TX: SV1.4, SV1.8, SV50.13
VIN: SV3.6, SV48.16
VIN-TEENSY: SV3.3, SV3.5, U$1.VIN

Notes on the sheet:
BENCHDUINO TEENSY 4.1 DAUGHTERBOARD

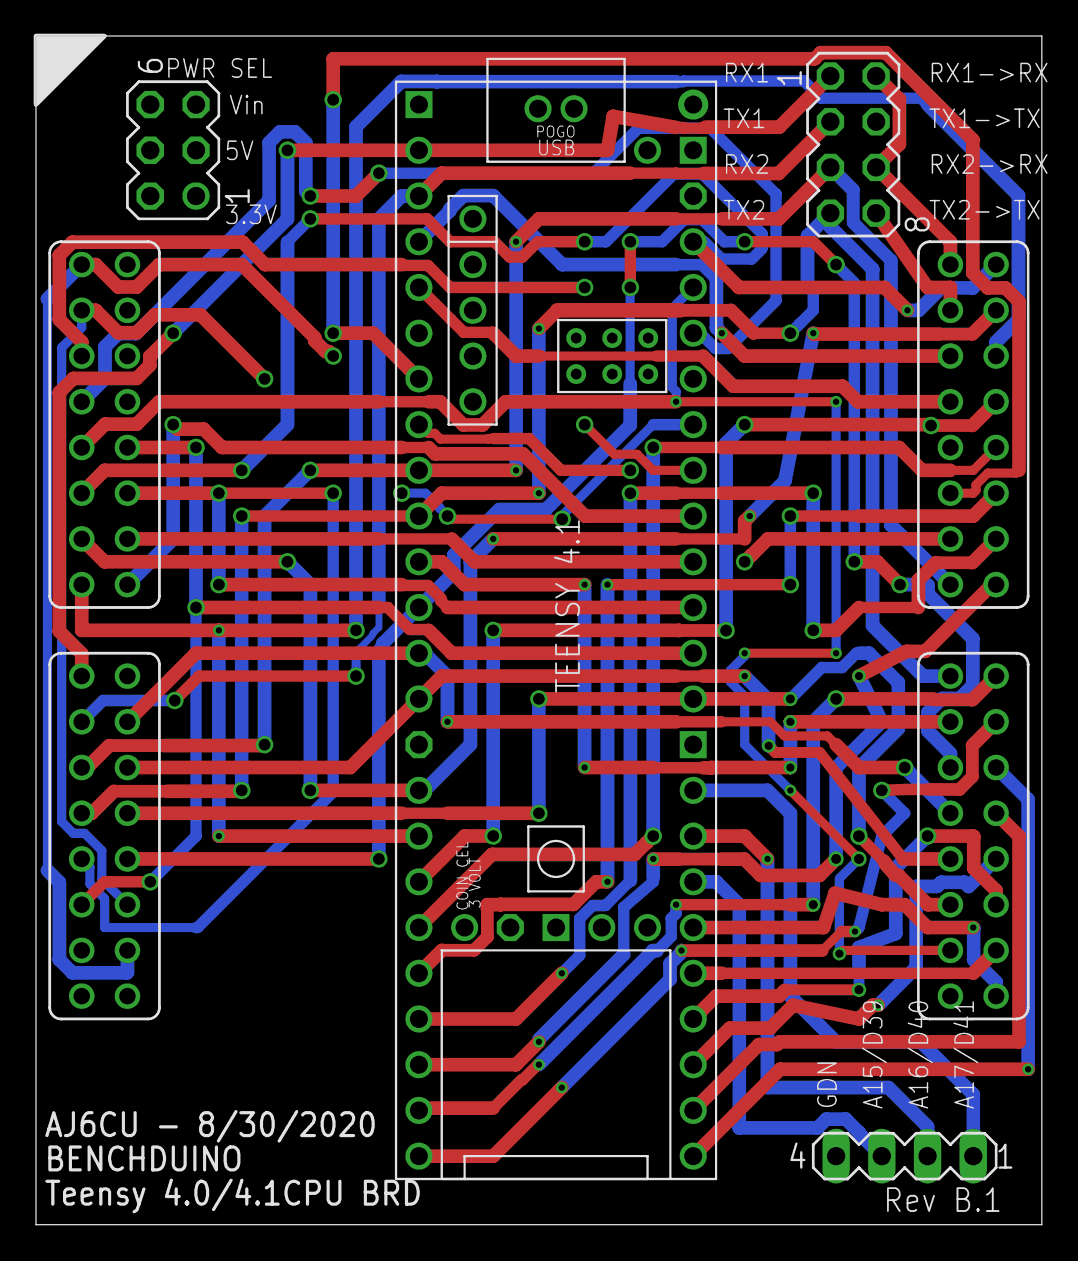
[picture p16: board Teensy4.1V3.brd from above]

Board: 4 copper layers, 55.9 x 66.0 mm, 8 parts (0 on the bottom side), 51 nets.

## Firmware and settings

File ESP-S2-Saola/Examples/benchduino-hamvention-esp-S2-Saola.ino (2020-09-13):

// ==============================================================================
// ==============================================================================
// Title:  BenchDuino Example 1.  Author:  George KJ6VU
// Morse code section based on the simple Morse Beacon by: Mark VandeWettering K6HX http://brainwagon.org
// Modified by Mark AJ6CU on Sept 13 for ESP-S2-Saola
// Specific board was:
// https://www.amazon.com/gp/product/B087T2NTD6/ref=ppx_yo_dt_b_search_asin_title?ie=UTF8&psc=1
//
//
// To use Arduino IDE must:
// 1. Set Board to ESP32 Dev Module
// 2. Upload speed 115200 (sometimes the 900k speeds works...)
// 3. Set partition size to Huge APP (3mb no  otw/1mb Spiffs) - this is because the BT library is so large...
//    even though we don't use it...
//

           char sw_version[10] = "1.0";
           int dbg = 0;
// ==============================================================================
// ==============================================================================
// Physical pin assignments 
// NOTE These are in terms of ESP32 GPIO pin#. Look in pin mapping, and then 
// See which GPIO pin# is associated with which Benchduino pin
// ==============================================================================
  const int PinA  = 2;         const int PinB  = 3;         const int PinSW = 4;    // Rotary encoder
  const int button1 = 5;
  const int button2 = 6;
  const int button3 = 7;
  const int button4 = 8;
  const int led1 = 9;
  const int led2 = 10;
  const int led3 = 11;  //Note that GPIO11-GPIO13 collide with SPI bus, don't use together...
  const int led4 = 12;
  const int statuspin   = 13;
  const int analogPin = 1;
  
  #define SDAPIN 39
  #define SCLPIN 40
  
//  const int beeperpin = 22;
// ==============================================================================
// Define Menu System text and control variables
// ==============================================================================
// LCD Menu array is 5 different windows with 2 lines.  Addressing starts at 0.
  int maxmenu = 5;
  String menu[6][2] {    
    {"Welcome         ","BenchDuino      "},  // Menu item #0 - Welcome splash screen
    {"Freq            ","LED LCD POT CW  "}}; // Menu item #1 - Demo items
    int current_menu = 0;  

struct t_mtab { char c, pat; } ;

struct t_mtab morsetab[] = {
  {'.', 106},{',', 115}, {'?', 76}, {'/', 41},
  {'A', 6},  {'B', 17}, {'C', 21},  {'D', 9},  {'E', 2},  {'F', 20},  {'G', 11},  {'H', 16},  {'I', 4},
  {'J', 30}, {'K', 13}, {'L', 18},  {'M', 7},  {'N', 5},  {'O', 15},  {'P', 22},  {'Q', 27},  {'R', 10},
  {'S', 8},  {'T', 3},  {'U', 12},  {'V', 24}, {'W', 14}, {'X', 25},  {'Y', 29},  {'Z', 19},  
  {'1', 62}, {'2', 60}, {'3', 56},  {'4', 48}, {'5', 32}, {'6', 33},  {'7', 35},  {'8', 39},  {'9', 47},  {'0', 63}
} ;

#define N_MORSE  (sizeof(morsetab)/sizeof(morsetab[0]))
#define SPEED  (20)
#define DOTLEN  (1200/SPEED)
#define DASHLEN  (3*(1200/SPEED))
// ==============================================================================
// Define radio and control head operating parameters
// ==============================================================================
  byte config_radio_address = 0xA2;
  byte config_controller_address = 0xE0;
  byte button_debounce_time = 500;
  unsigned long freq = 7100;
  unsigned long lastFreq = freq;
  unsigned long freqStep = 1;
  int button1_val;  int button2_val;  int button3_val;  int button4_val;
// ==============================================================================
// Define global variables
// ==============================================================================
  int i = 0;
  int j = 0;
  int x = 0;
  int y = 0;
  String cmd;
  String arg[10];
  int parser_stringlen = 0;
  int parser_strstart = 0;
  int parser_strstop = 0;
  int parser_numargs = 0;
  int parser_argstart[10];
  int parser_argend[10];
  int parser_argnum = 0;
  String str = ""; // create a string
  byte inbyte;
  const byte numChars = 101;
  char receivedChars[numChars];
  boolean newData = false;
  int data =0;
  String outdata;
  String my_address_string;
  String next_arg;
  String payload;
  String intoaddress;
  char boardtype[3];
  int packetlen = 0;
  int stringlen; // String length
  char my_address[2] = {'0', '0'};
  int toaddress_match = 0;
  int delimiter1_match = 0;
  int delimiter2_match = 0;
  int fromaddress_match = 0;
  int goodpacket = 0;
  int directpacket = 0;
  String command;
  int diditflag = 0;
  int val = 0;
  int my_address_value = 0;
  int lastCount = 0;
  volatile int virtualPosition = 0;
  uint8_t draw_state = 2;
  float freqfloat = 0;
// ==============================================================================
// Import libraries
// ==============================================================================
  #include <U8g2lib.h>           //replaces U8glib
  #define U8X8_HAVE_HW_I2C
  #include <Wire.h>
  
// Had problems with the "NewLiquidCrystal_I2C" library and had to drop back
// to the "standard" one
  #include <LiquidCrystal_I2C.h> 

  
 
// ==============================================================================
// Device address assignments
// ==============================================================================
  int lcd_addr    = 0x27;  // LCD address.  Typicaly 0x27 or 0x3F
// ==============================================================================
// Initialize displays 
// ==============================================================================
 // LiquidCrystal_I2C  lcd(lcd_addr,2,1,0,4,5,6,7);
 LiquidCrystal_I2C lcd(0x27, 16, 2); 

 typedef u8g2_uint_t u8g_uint_t;   //avoids lots of code changes
 U8G2_SSD1306_128X64_NONAME_F_HW_I2C u8g(U8G2_R0,SCLPIN,SDAPIN, U8X8_PIN_NONE);
 

  
// ==============================================================================
// INTERRUPT
// ==============================================================================
 void isr ()  {
  static unsigned long lastInterruptTime = 0;
  unsigned long interruptTime = millis();
  if (interruptTime - lastInterruptTime > 5) {      // If interrupts come slower than 5ms, we assume it's good data
    if (digitalRead(PinB) == LOW) {freq = freq - freqStep ;}  else  {freq = freq + freqStep;}
  }
  lastInterruptTime = interruptTime;    // Keep track of when we were here last (no more than every 5ms)
}


// ==============================================================================
// ==============================================================================
// ===== SETUP =====
// ==============================================================================
// ==============================================================================
void setup() {
  Serial.begin(115200);
//  Serial1.begin(9600);  // Never tested the CAT out. So just commented it out.
// ==============================================================================
// Set pin modes
// ==============================================================================

    pinMode(PinA, INPUT);  pinMode(PinB, INPUT);  pinMode(PinSW, INPUT_PULLUP);
    pinMode(led1, OUTPUT);
    pinMode(led2, OUTPUT);
    pinMode(led3, OUTPUT);
    pinMode(led4, OUTPUT);
    pinMode(statuspin, OUTPUT);
    pinMode(button1, INPUT);
    pinMode(button2, INPUT); 
    pinMode(button3, INPUT); 
    pinMode(button4, INPUT); 
    digitalWrite(led1,LOW);
    digitalWrite(led2,LOW);
    digitalWrite(led3,LOW);
    digitalWrite(led4,LOW); 

   
// ==============================================================================
    attachInterrupt(digitalPinToInterrupt(PinA), isr, RISING);
 // Serial1.print("STARTUP  Version ");
 // Serial1.println(sw_version);
  outdata = "/";
  my_address_string = "00";
  next_arg = "";
  payload = "";
  Serial.print("setting sda/scl");
  Wire.begin(SDAPIN,SCLPIN);

//=== LCD SETUP =================================================================
  // lcd.setBacklightPin(3,POSITIVE);  lcd.setBacklight(HIGH);  
  lcd.init();
  lcd.backlight();
  lcd.begin(16, 2);  lcd.clear();

  u8g.begin();
  do_update_lcd(current_menu);  delay(1000);       // SPLASH SCREEN
  current_menu = 1;  do_update_lcd(current_menu);  // Jump to first screen

  digitalWrite(led1,HIGH);
  digitalWrite(led2,HIGH);
  digitalWrite(led3,HIGH);
  digitalWrite(led4,HIGH);
  digitalWrite(statuspin,HIGH);
}

// ==============================================================================
// ==============================================================================
// ===== MAIN LOOP =====
// ==============================================================================
// ==============================================================================
void loop() 
{

 // recvWithStartEndMarkers();
 // processpayload();

  button1_val = digitalRead(button1);  if (button1_val==LOW and current_menu==1) { do_button11(); }
  button2_val = digitalRead(button2);  if (button2_val==LOW and current_menu==1) { do_button12(); }
  button3_val = digitalRead(button3);  if (button3_val==LOW and current_menu==1) { do_button13(); }
  button4_val = digitalRead(button4);  if (button4_val==LOW and current_menu==1) { do_button14(); }
//
// Had to add this to turn back on led's after execution of the command. Not
// needed for other MCU's. Not sure why...
//
  digitalWrite(led1,HIGH);
  digitalWrite(led2,HIGH);
  digitalWrite(led3,HIGH);
  digitalWrite(led4,HIGH);

  if ((!digitalRead(PinSW))) { freq = 7100;  while (!digitalRead(PinSW))  delay(200); }
  if (freq != lastFreq) { Serial.println(freq);  /* Serial1.println(freq); */    lcd.setCursor (5,0); lcd.print(String (freq));   }   lastFreq = freq; // Keep track of this new value 
  


 
/// OLED picture loop  
  u8g.firstPage();  
   
  do 
  {
    draw();
  } while( u8g.nextPage() );
  
  // increase the state
  draw_state++;
  if ( draw_state >= 9*8 )
    draw_state = 0; 
    
}

// ==============================================================================
// ==============================================================================
// ===== SUBROUTINES =====
// ==============================================================================
// ==============================================================================


//-------------------------------------------------------------------------------
void send_msg(String outtext) {
  Serial.println(outtext);
  //Serial1.println(outtext);
return;
}

//----- LCD SUBROUTINES ---------------------------------------------------------
void do_update_lcd(int menu_item) {
  lcd.setCursor (0,0);  lcd.print(menu[menu_item][0]);
  lcd.setCursor (0,1);  lcd.print(menu[menu_item][1]);
  lcd.setCursor (5,0);  lcd.print(String (freq));
  }

//------ MENU 1 BUTTON 1 --------------------------------------------------------
  void do_button11()  { 
    send_msg("M1B1");
    Serial.println("button 1 pressed"); 
    debounce(1);
    lcd.setCursor (0,0);  lcd.print("BenchDuino      "); 
    lcd.setCursor (0,1);  lcd.print("LED Test        "); 
    for (i=0;i<=4;i++) {
      y = 100;
      int z = 0;
      digitalWrite(led1,HIGH);  delay(y);  digitalWrite(led1,LOW);  delay(z);
      digitalWrite(led2,HIGH);  delay(y);  digitalWrite(led2,LOW);  delay(z);
      digitalWrite(led3,HIGH);  delay(y);  digitalWrite(led3,LOW);  delay(z);
      digitalWrite(led4,HIGH);  delay(y);  digitalWrite(led4,LOW);  delay(z);
    }
    lcd.clear();  do_update_lcd(1); 
  }
//------ MENU 1 BUTTON 2 ---------------------------------------------------------------
  void do_button12()  { 
    send_msg("M1B2");  
    debounce(2);
    lcd.clear();
    lcd.setCursor (0,0);  lcd.print("BenchDuino      "); 
    lcd.setCursor (0,1);  lcd.print("Dev Board       "); 
    delay(2000);
    lcd.setCursor (0,0);  lcd.print("Design your own "); 
    lcd.setCursor (0,1);  lcd.print("project easily !"); 
    delay(2000);
    lcd.clear();  do_update_lcd(1);
    }
//------ MENU 1 BUTTON 3 ---------------------------------------------------------------
  void do_button13()  {  
    send_msg("M1B3"); 
    debounce(3);
    lcd.clear();
    lcd.setCursor (0,0);  lcd.print("Pot value"); 
    lcd.setCursor (12,1);  lcd.print("EXIT"); 
    while (digitalRead(button4)==HIGH) {
      
      
      int val = 0;  // variable to store the value read
      val = analogRead(analogPin);  // read the input pin
      lcd.setCursor (10,0);  lcd.print("    "); 
      // Following fixes an apparent bug in original code where
      // value of the pot was not echoed to the serial port
      lcd.setCursor (10,0);  lcd.print(String (val)); 
      Serial.println("x=" + String(val));
      delay(500);
      }
      debounce(4);
      lcd.clear();  do_update_lcd(1);
    }
//------ MENU 1 BUTTON 4 ---------------------------------------------------------------
  void do_button14()  { 
    send_msg("M1B4"); 
    debounce(4);
    lcd.clear();
    lcd.setCursor (0,0);  lcd.print("Sending CW      ");   
    lcd.setCursor (0,1);  lcd.print("CQ DE KJ6VU     ");
    sendcw("CQ CQ CQ DE KJ6VU");
    lcd.clear();  do_update_lcd(1);
    }


// Did test Call, all commented out
//---------------------------------------------------------------
//--- RECEIVE Serial1 DATA ---------------------------------------
/* void recvWithStartEndMarkers() {
    static boolean recvInProgress = false;
    static byte ndx = 0;
    char startMarker = '/';
    char endMarker1 = 13;
    char endMarker2 = 10;
    char rc;
    while (Serial.available() > 0 && newData == false) {
        rc = Serial.read();
        if (recvInProgress == true) {
            if (rc != endMarker1 and rc != endMarker2)  {
                receivedChars[ndx] = rc;
                ndx++;
                if (ndx >= numChars) {
                    ndx = numChars - 1;
                }
            }
            else {
                receivedChars[ndx] = '\0'; // terminate the string
                recvInProgress = false;
                ndx = 0;
                newData = true;
            }
        }
        else if (rc == startMarker) {
            recvInProgress = true;
        }
    }
}

//--- COMMAND PROCESSING  ----------------------------------------
void processpayload() {
  if (newData == true) {
  String str(receivedChars);
  str.toUpperCase();
  stringlen = str.length();
  command = str;
  parser_stringlen = command.length();
  x = command.indexOf(",");
  cmd = command.substring(0,x);
  // Determine how many arguments there are and store it in numargs
  parser_numargs = 0;
  for (int i=0;i<=parser_stringlen;i++) {
    if (command.substring(i,i+1).equals(",")) {
      parser_numargs++;
      parser_argstart[parser_numargs] = i+1;
      parser_argend[parser_numargs-1] = i;
    }
  }

  for (int i=1;i<=parser_numargs-1;i++) {
    x=i;
    arg[i] = command.substring(parser_argstart[i],parser_argend[i]);
  }

    x++;
    arg[x] = command.substring(command.lastIndexOf(",")+1);

//=== COMMAND TABLE =========================================================
  if (dbg==1)  Serial1.println("Command >" + command + "<");
  if (cmd.equals("PING")) { diditflag=1; send_msg("PING!");}
  if (cmd.equals("LCD"))   { do_set_lcd(); }
  if (cmd.equals("MENU"))  { do_set_menu(); }
  
  if (diditflag == 1) {
  //--- ASSEMBLE PAYLOAD --------------------------------------------
  payload = "-";
  //--- ASSEMBLE PACKET ---------------------------------------------
  outdata = payload;                  // Start of packet
  //--- SENT PACKET -------------------------------------------------
  send_msg(outdata);
  digitalWrite(statuspin,HIGH);
  delay (250);
  digitalWrite(statuspin,LOW);
  diditflag = 0;
  }
  diditflag = 0;
  command = "";
  goodpacket = 0;
  directpacket = 0;
  newData = false;
    }
}
*/

//-------------------------------------------------------------------
//-------------------------------------------------------------------
void do_set_led(String mode) {
  // command format:  LCD,1,2,TEXT  LCD,Line number 1..2, character position 1..16, text
  if (mode == "1") {  digitalWrite(statuspin,HIGH);  }  
  if (mode == "0") { /*digitalWrite(statuspin,LOW); */}
  if (mode == "B") { 
     digitalWrite(statuspin,LOW);   delay(200); 
    digitalWrite(statuspin,HIGH);  delay(200); 
    digitalWrite(statuspin,LOW);   delay(50); 
    digitalWrite(statuspin,HIGH);  delay(200); 
    digitalWrite(statuspin,LOW); 
  }
}
//-------------------------------------------------------------------
void do_set_lcd() {
  // command format:  LCD,1,2,TEXT  LCD,Line number 1..2, character position 1..16, text
  if (dbg==1)  /*Serial1.println("arg 1 = " + arg[1] + ", arg 2 = " + arg[2])*/;
  lcd.setCursor (arg[2].toInt()-1,arg[1].toInt()-1);
  lcd.print(arg[3]);
}
//-------------------------------------------------------------------
void debounce(int x)  {
    if (x==1) {do {delay(button_debounce_time);} while (digitalRead(button1)==LOW); } // Debounce the button
    if (x==2) {do {delay(button_debounce_time);} while (digitalRead(button2)==LOW); } // Debounce the button
    if (x==3) {do {delay(button_debounce_time);} while (digitalRead(button3)==LOW); } // Debounce the button
    if (x==4) {do {delay(button_debounce_time);} while (digitalRead(button4)==LOW); } // Debounce the button
}
//-------------------------------------------------------------------
void do_set_menu() {
  // menu[A][B]  A=Slot, B=Row
  if (arg[1]=="1" and arg[2]=="1") {menu[1][2]=arg[3];}
  if (arg[1]=="2" and arg[2]=="2") {menu[1][2]=arg[3];}
  do_update_lcd(current_menu);
}


//=========================================================================
//===== OLED GRAPHICS ROUTINES ============================================
//=========================================================================

//
// Note that the u8g2lib is less fuctional than the original u8glib. So
// Had to comment out several features (i.e. RGB, forground color, etc.)
//
 void u8g_prepare(void) 
{
  u8g.setFont(u8g_font_6x10);
  u8g.setFontRefHeightExtendedText();
//  u8g.setDefaultForegroundColor();
  u8g.setFontPosTop();
}

void intro(uint8_t a)
{
  u8g.setFont(u8g_font_unifont);
  u8g.drawStr(12, 19, "Welcome");
  u8g.drawStr(12, 38, "To");
  u8g.drawStr(12, 57, "BenchDuino :)");
}

void u8g_box_frame(uint8_t a) 
{
  u8g.drawStr( 12, 0, "BenchDuino");
  u8g.drawBox(5,10,30,20);
  u8g.drawBox(10+a,15,40,17);
  u8g.drawStr( 12, 35, "BenchDuino");
  u8g.drawFrame(5,10+38,20,10);
  u8g.drawFrame(10+a,15+38,30,7);
}

void u8g_disc_circle(uint8_t a) 
{
  u8g.drawStr( 12, 0, "BenchDuino");
  u8g.drawDisc(11,18,9);
  u8g.drawDisc(24+a,16,7);
  u8g.drawStr(12, 35, "BenchDuino");
  u8g.drawCircle(11,18+35,9);
  u8g.drawCircle(24+a,16+35,7);
}

void u8g_r_frame(uint8_t a) 
{
  u8g.drawStr( 12, 0, "BenchDuino");
  u8g.drawRFrame(5, 15,40,30, a+1);
  u8g.drawRBox(50, 15,25,40, a+1);
}

void u8g_string(uint8_t a) 
{
  /*u8g.drawStr270(64,31-a, "BenchDuino");
  u8g.drawStr(64+a,31, "BenchDuino");
  u8g.drawStr90(64,31+a, "BenchDuino");
  u8g.drawStr180(64-a,31, "BenchDuino");*/
  u8g.setFontDirection(3); // 270 degrees
  u8g.drawStr(64,31-a, "BenchDuino");
  u8g.drawStr(64+a,31, "BenchDuino");
  u8g.setFontDirection(1);  //90 degrees
  u8g.drawStr(64,31+a, "BenchDuino");
  u8g.setFontDirection(2);  //180 degrees
  u8g.drawStr(64-a,31, "BenchDuino");
}

void u8g_line(uint8_t a) 
{
  u8g.drawStr( 12, 0, "BenchDuino");
  u8g.drawLine(7+a, 15, 40, 55);
  u8g.drawLine(7+a*2, 15, 60, 55);
  u8g.drawLine(7+a*3, 15, 80, 55);
  u8g.drawLine(7+a*4, 15, 100, 55);
}

void u8g_extra_page(uint8_t a)
{
//  if ( u8g.getMode() == U8G_MODE_HICOLOR || u8g.getMode() == U8G_MODE_R3G3B2) {
    // draw background (area is 128x128) 
 /*   u8g_uint_t r, g, b;
    b = a << 5;
    for( g = 0; g < 64; g++ )
    {
      for( r = 0; r < 64; r++ )
      {
  u8g.setRGB(r<<2, g<<2, b );
  u8g.drawPixel(g, r);
      }
    }
    u8g.setRGB(255,255,255);
    u8g.drawStr( 66, 0, "Color Page");
  }
  else if ( u8g.getMode() == U8G_MODE_GRAY2BIT )
  {
    u8g.drawStr( 66, 0, "Gray Level");
    u8g.setColorIndex(1);
    u8g.drawBox(2, 4, 64, 32);    
    u8g.drawBox(70, 20, 4, 12);
    u8g.setColorIndex(2);
    u8g.drawBox(2+1*a, 4+1*a, 64-2*a, 32-2*a);
    u8g.drawBox(74, 20, 4, 12);
    u8g.setColorIndex(3);
    u8g.drawBox(2+2*a, 4+2*a, 64-4*a, 32-4*a);
    u8g.drawBox(78, 20, 4, 12);
  }
  else
  {
  */
    u8g.drawStr( 2, 9, "BenchDuino");
    // u8g.setScale2x2();
    u8g.drawStr( 1,14+a, "CQ CQ CQ");
    // u8g.undoScale();
//  }
}


void draw(void) 
{
  u8g_prepare();
  switch(draw_state >> 3) {
    case 0: intro(draw_state&7); break;
    case 1: u8g_box_frame(draw_state&7); break;
    case 2: u8g_disc_circle(draw_state&7); break;
    case 3: u8g_r_frame(draw_state&7); break;
    case 4: u8g_string(draw_state&7); break;
    case 5: u8g_line(draw_state&7); break;
    case 6: u8g_extra_page(draw_state&7); break;
  }
}






//=========================================================================
//  CW SENDING ROUTINES
//  Based on the simple Morse Beacon by: Mark VandeWettering K6HX http://brainwagon.org
//=========================================================================


void dash()
{
  digitalWrite(led1, HIGH);  digitalWrite(led2, HIGH);  digitalWrite(led3, HIGH); digitalWrite(led4, HIGH);  /* digitalWrite(beeperpin, HIGH); */   
  delay(DASHLEN);
  digitalWrite(led1, LOW); digitalWrite(led2, LOW); digitalWrite(led3, LOW); digitalWrite(led4, LOW) ;  /* digitalWrite(beeperpin, LOW); */ 
  delay(DOTLEN) ;
}

void dit()
{
  digitalWrite(led1, HIGH);  digitalWrite(led2, HIGH);  digitalWrite(led3, HIGH); digitalWrite(led4, HIGH);  /* digitalWrite(beeperpin, HIGH); */   
  delay(DOTLEN);
  digitalWrite(led1, LOW); digitalWrite(led2, LOW); digitalWrite(led3, LOW); digitalWrite(led4, LOW) ;  /* digitalWrite(beeperpin, LOW); */
  delay(DOTLEN);
}
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

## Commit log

2020-08-25 added STM32 Folder
2020-08-25 Eagle files for Teensy 4.x added
    [Teensy4.1V3.brd, Teensy4.1V3.sch]
2020-08-25 adding schematic and photo
2020-08-30 Updated Teensy to correct power error
    [Teensy4.1V3.brd, Teensy4.1V3.sch]
2020-08-31 Added STM32
    [STM32BluePill.brd, STM32BluePill.sch]
2020-08-31 fix kicad spelling
2020-08-31 add back in pcb
2020-08-31 deleted pcb for rename
2020-08-31 add back in pcbdesign
2020-08-31 file structued pushed for esp32
2020-08-31 added board models/photos
